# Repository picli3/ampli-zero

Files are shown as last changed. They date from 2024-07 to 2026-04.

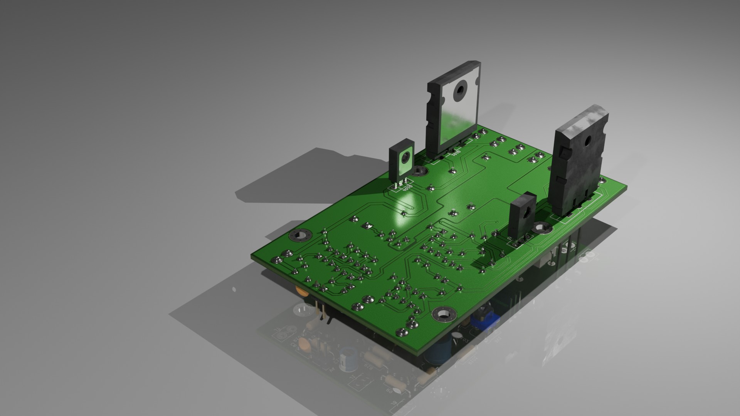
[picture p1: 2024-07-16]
iso_2.jpg

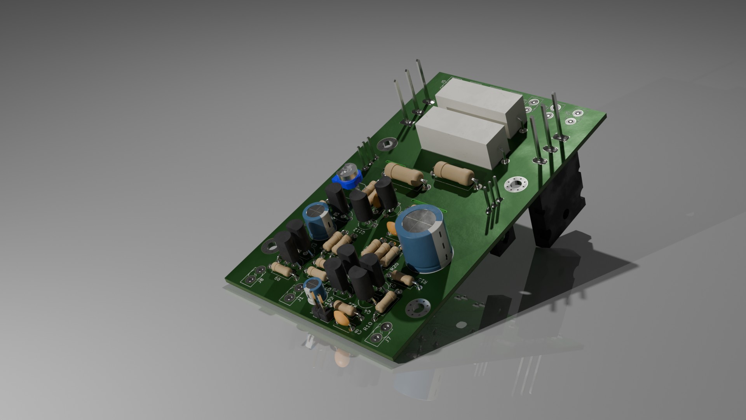
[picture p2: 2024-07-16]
iso_1.jpg

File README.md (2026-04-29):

# ampli-zero

Proyecto de amplificador de audio orientado a una implementación compacta y práctica, pensado como base para experimentar o construir una etapa de amplificación en PCB usando KiCad.

## Qué incluye
- esquemáticos o archivos de diseño en KiCad
- PCB o documentación asociada
- base reutilizable para análisis, fabricación o mejora del proyecto

## Propósito general
Este repositorio busca concentrar el diseño de hardware del proyecto en un formato editable y reutilizable, facilitando pruebas, documentación y futuras iteraciones del circuito.

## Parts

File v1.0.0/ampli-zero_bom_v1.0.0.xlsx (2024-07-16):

Item | References | Description | Qty | Package | Value | Aditional
1 | C7 | Unpolarized capacitor | 1 | C_Disc_D5.0mm_W2.5mm_P5.00mm | 100p | >100V
2 | C5 | Unpolarized capacitor | 1 | C_Disc_D5.0mm_W2.5mm_P5.00mm | 150p | >100V
3 | C8 | Unpolarized capacitor | 1 | C_Disc_D5.0mm_W2.5mm_P5.00mm | 100n | >100V
4 | C102 | Unpolarized capacitor | 1 | CP_Radial_D5.0mm_P2.50mm | 3.3u
5 | C3 | Polarized capacitor, US symbol | 1 | CP_Radial_D5.0mm_P2.50mm | 10u | >100V
6 | C6 | Polarized capacitor, US symbol | 1 | CP_Radial_D10.0mm_P5.00mm | 220u | >100V
7 | Q2 Q3 Q7 Q8 Q102 | PNP transistor, emitter/base/collector | 5 | TO-92L_Inline_Wide | 2N5401
8 | Q4 Q5 Q9 Q112 | NPN transistor, emitter/base/collector | 4 | TO-92L_Inline_Wide | 2N5551
9 | Q101 | PNP transistor, base/collector/emitter | 1 | TO-264-3_Vertical | 2SA1943
10 | Q104 | PNP transistor, emitter/collector/base | 1 | TO-126-3_Vertical | 2SB649
11 | Q10 | NPN transistor, base/collector/emitter | 1 | TO-264-3_Vertical | 2SC5200
12 | Q103 | NPN transistor, emitter/collector/base | 1 | TO-126-3_Vertical | 2SD669
13 | R105 R106 | Resistor, US symbol | 2 | R_Axial_Power_L25.0mm_W9.0mm_P27.94mm | 0.33 | 5W
14 | R21 | Resistor, US symbol | 1 | R_Axial_DIN0207_L6.3mm_D2.5mm_P10.16mm_Horizontal | 22 | 1/2W
15 | R103 R104 | Resistor, US symbol | 2 | R_Axial_DIN0414_L11.9mm_D4.5mm_P15.24mm_Horizontal | 33 | 1W
16 | R10 R15 | Resistor, US symbol | 2 | R_Axial_DIN0207_L6.3mm_D2.5mm_P10.16mm_Horizontal | 68 | 1/2W
17 | R11 R18 R101 | Resistor, US symbol | 3 | R_Axial_DIN0207_L6.3mm_D2.5mm_P10.16mm_Horizontal | 100 | 1/2W
18 | R9 | Resistor, US symbol | 1 | R_Axial_DIN0207_L6.3mm_D2.5mm_P10.16mm_Horizontal | 150 | 1/2W
19 | R19 | Resistor, US symbol | 1 | R_Axial_DIN0207_L6.3mm_D2.5mm_P10.16mm_Horizontal | 220 | 1/2W
20 | R116 | Resistor, US symbol | 1 | R_Axial_DIN0207_L6.3mm_D2.5mm_P10.16mm_Horizontal | 330 | 1/2W
21 | R14 R20 | Resistor, US symbol | 2 | R_Axial_DIN0207_L6.3mm_D2.5mm_P10.16mm_Horizontal | 1k | 1/2W
22 | R115 | Resistor, US symbol | 1 | R_Axial_DIN0207_L6.3mm_D2.5mm_P10.16mm_Horizontal | 1.2k | 1/2W
23 | R13 R22 | Resistor, US symbol | 2 | R_Axial_DIN0207_L6.3mm_D2.5mm_P10.16mm_Horizontal | 10k | 1/2W
24 | R12 | Resistor, US symbol | 1 | R_Axial_DIN0207_L6.3mm_D2.5mm_P10.16mm_Horizontal | 12k | 1/2W
25 | R23 | Resistor, US symbol | 1 | R_Axial_DIN0207_L6.3mm_D2.5mm_P10.16mm_Horizontal | 91.13k | 1/2W

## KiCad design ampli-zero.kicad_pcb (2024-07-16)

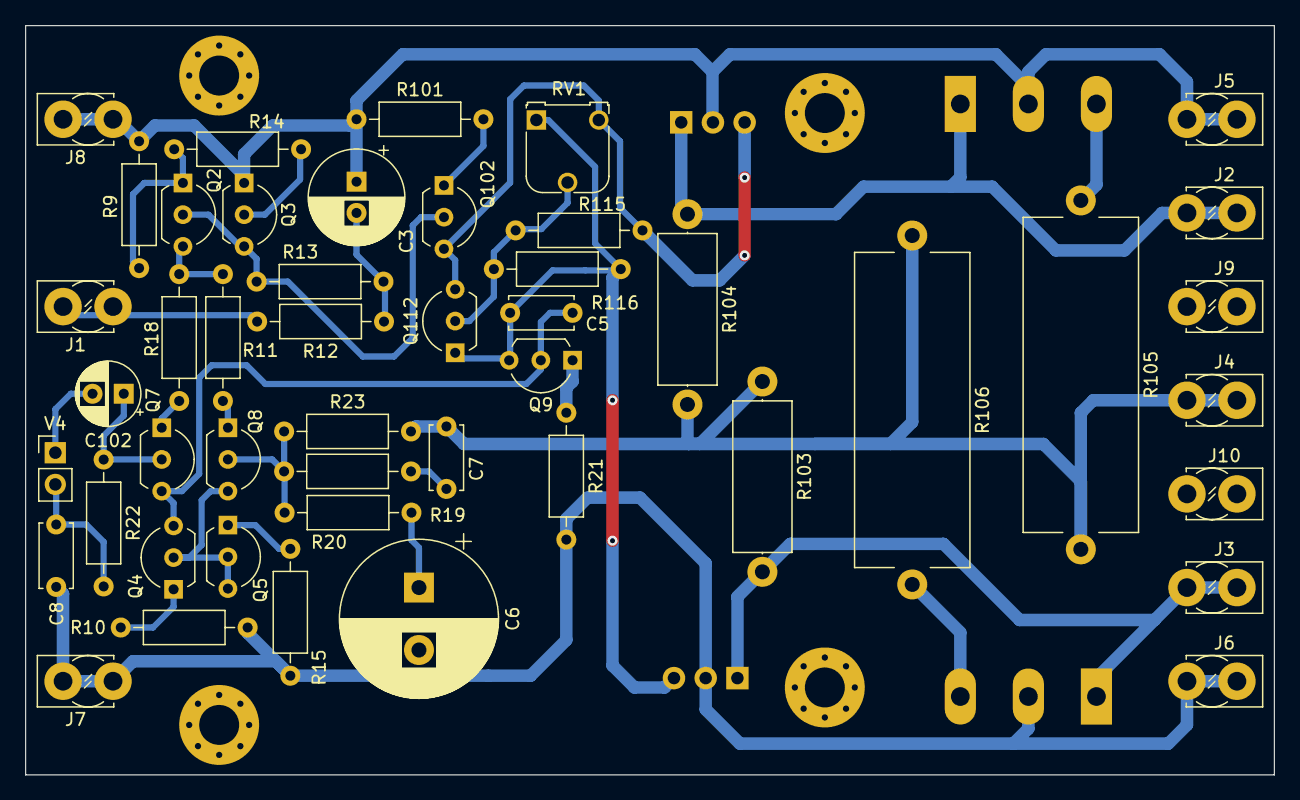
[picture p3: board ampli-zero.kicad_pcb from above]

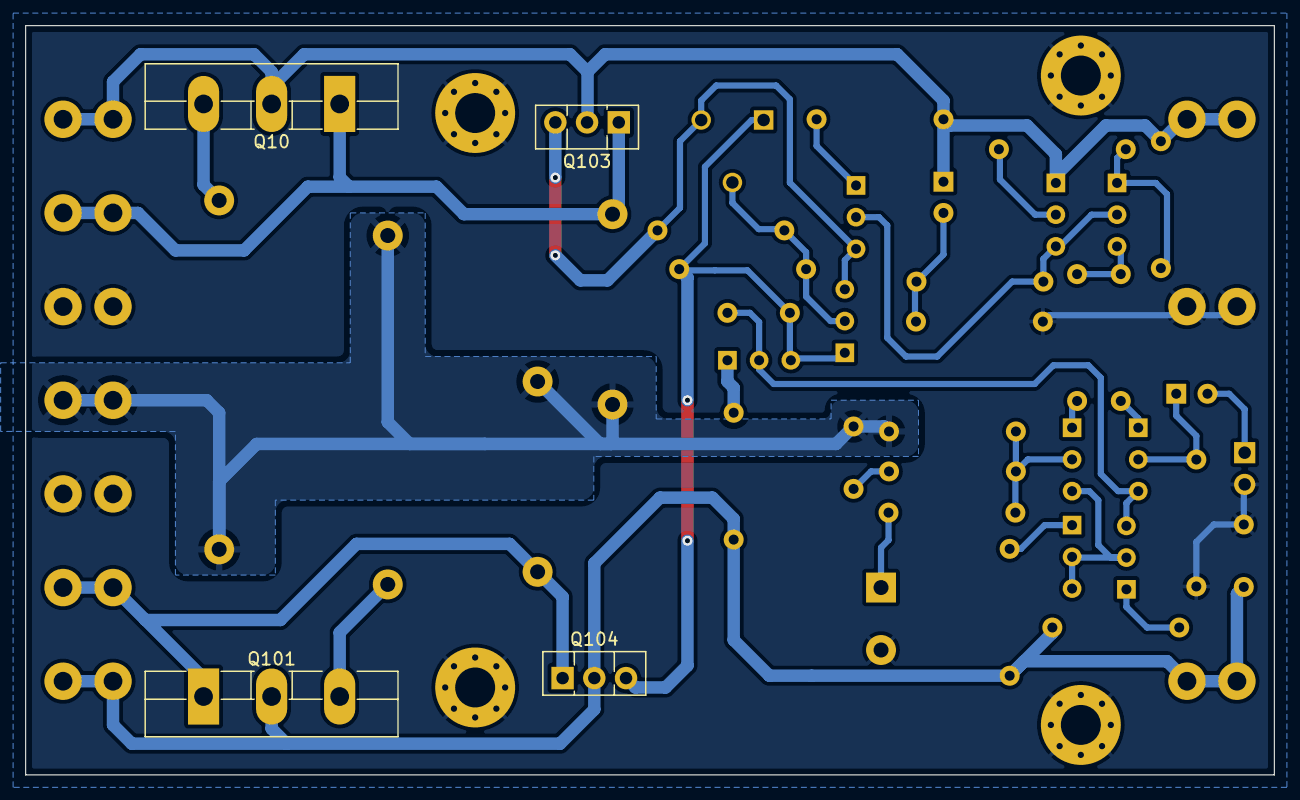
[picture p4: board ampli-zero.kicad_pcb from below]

Board: 2 copper layers, 100.0 x 60.0 mm, 55 parts (4 on the bottom side), 29 nets.

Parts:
C3: 10u; CP_Radial_D7.5mm_P2.50mm
C5: 150p; C_Disc_D5.0mm_W2.5mm_P5.00mm
C6: 220u; CP_Radial_D12.5mm_P5.00mm
C7: 100p; C_Disc_D5.0mm_W2.5mm_P5.00mm
C8: 100n; C_Disc_D5.0mm_W2.5mm_P5.00mm
C102: 3.3u; CP_Radial_D5.0mm_P2.50mm
H1, H2, H3, H4: MountingHole_Pad; MountingHole_3.2mm_M3_Pad_Via
J1, J2, J3, J4, J5, J6, J7, J8, J9, J10: Conn_01x01; TerminalBlock_MetzConnect_360322_1x01_Horizontal_ScrewM3.0_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
Q2, Q3, Q7, Q8, Q102: 2N5401; TO-92L_Inline_Wide
Q4, Q5, Q9, Q112: 2N5551; TO-92L_Inline_Wide
Q10: 2SC5200; TO-264-3_Vertical
Q101: 2SA1943; TO-264-3_Vertical
Q103: 2SD669; TO-126-3_Vertical
Q104: 2SB649; TO-126-3_Vertical
R9: 150; R_Axial_DIN0207_L6.3mm_D2.5mm_P10.16mm_Horizontal
R10, R15: 68; R_Axial_DIN0207_L6.3mm_D2.5mm_P10.16mm_Horizontal
R11, R18, R101: 100; R_Axial_DIN0207_L6.3mm_D2.5mm_P10.16mm_Horizontal
R12: 12k; R_Axial_DIN0207_L6.3mm_D2.5mm_P10.16mm_Horizontal
R13, R22: 10k; R_Axial_DIN0207_L6.3mm_D2.5mm_P10.16mm_Horizontal
R14, R20, R116: 1k; R_Axial_DIN0207_L6.3mm_D2.5mm_P10.16mm_Horizontal
R19: 220; R_Axial_DIN0207_L6.3mm_D2.5mm_P10.16mm_Horizontal
R21: 22; R_Axial_DIN0207_L6.3mm_D2.5mm_P10.16mm_Horizontal
R23: 91.13k; R_Axial_DIN0207_L6.3mm_D2.5mm_P10.16mm_Horizontal
R103, R104: 33; R_Axial_DIN0414_L11.9mm_D4.5mm_P15.24mm_Horizontal
R105, R106: 0.33; R_Axial_Power_L25.0mm_W9.0mm_P27.94mm
R115: 1; R_Axial_DIN0207_L6.3mm_D2.5mm_P10.16mm_Horizontal
RV1: 5k; Potentiometer_Runtron_RM-065_Vertical
V4: 1.76Vrms; PinHeader_1x02_P2.54mm_Vertical

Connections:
+107: C3.1, J5.1, J8.1, Q3.1 (E), Q10.2 (C), Q103.2 (C), R9.1, R101.1
-107: C8.1, J6.1, J7.1, Q101.2 (C), Q104.2 (C), R10.2, R15.2, R21.2
/FB: C7.2, J4.1, R23.2, R103.1, R104.2, R105.2, R106.1
/VB2: Q2.2 (B), Q3.3 (C), Q102.2 (B), R13.1
/VC2: Q2.3 (C), R11.1, R18.1
/VE2: Q2.1 (E), R9.2, R14.1
/gndv: C3.2, R12.1, R13.2
/v4i: C102.2, V4.1
/vdb: C5.2, Q9.3 (C), Q104.3 (B), Q112.1 (E), R116.2, RV1.1
/vdt: Q102.3 (C), Q103.3 (B), Q112.3 (C), R115.1, RV1.3
GND: C6.2, C8.2, H1.1, H2.1, H3.1, H4.1, J1.1, J9.1, J10.1, R12.2, R22.2, V4.2
unnamed: C6.1, R20.1
unnamed: C7.1, R19.2
unnamed: J2.1, Q10.1 (B), Q103.1 (E), R104.1
unnamed: J3.1, Q101.1 (B), Q104.1 (E), R103.2
unnamed: Q3.2 (B), R14.2
unnamed: Q4.2 (B), Q5.2 (B), Q5.3 (C), Q8.3 (C)
unnamed: C5.1, Q4.3 (C), Q7.3 (C), Q9.2 (B)
unnamed: Q4.1 (E), R10.1
unnamed: Q5.1 (E), R15.1
unnamed: C102.1, Q7.2 (B), R22.1
unnamed: Q7.1 (E), R18.2
unnamed: Q8.2 (B), R19.1, R20.2, R23.1
unnamed: Q8.1 (E), R11.2
unnamed: Q9.1 (E), R21.1
unnamed: Q10.3 (E), R105.1
unnamed: Q101.3 (E), R106.2
unnamed: Q102.1 (E), R101.2
unnamed: Q112.2 (B), R115.2, R116.1, RV1.2

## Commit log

2023-12-25 amplificador completado
    [ampli-zero.kicad_pcb, ampli-zero.kicad_sch]
2024-01-04 version de 32V
    [ampli-zero.kicad_pcb, ampli-zero.kicad_sch]
2024-01-06 version que enviada J Angel
    [ampli-zero.kicad_pcb, ampli-zero.kicad_sch]
2024-07-16 version desplegada sin probar
    [ampli-zero.kicad_pcb, ampli-zero.kicad_sch, ampli-zero_bom_v1.0.0.xlsx]
2024-07-16 agregando potenciometro
    [ampli-zero.kicad_pcb, ampli-zero.kicad_sch]
2024-07-16 enviado a pcbway
    [ampli-zero-B_Cu.gbr, ampli-zero-B_Fab.gbr, ampli-zero-B_Mask.gbr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]
